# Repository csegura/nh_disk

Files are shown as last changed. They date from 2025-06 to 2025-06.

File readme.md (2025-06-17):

# NorthStar Advantage Hard Disk

This repository is made with the aim of completing a HardDisk Card for the NorthStar Advantage system. 

The idea is use a microcontroller (pi pico) to emulate a disk drive, allowing the NorthStar Advantage to read and write to a disk image stored on an SD card.

This is an ambitious project, as the NorthStar Advantage system is quite old and has a unique architecture, but it is a fun challenge. I am an enthusiast of retro computing and I want to see if I can make this work. So any help will be welcome.

Outside sure there a lot of other enthusiasts that would like to see this project completed, so welcome to the project!

## Current status

- The project is in the early stages of development.

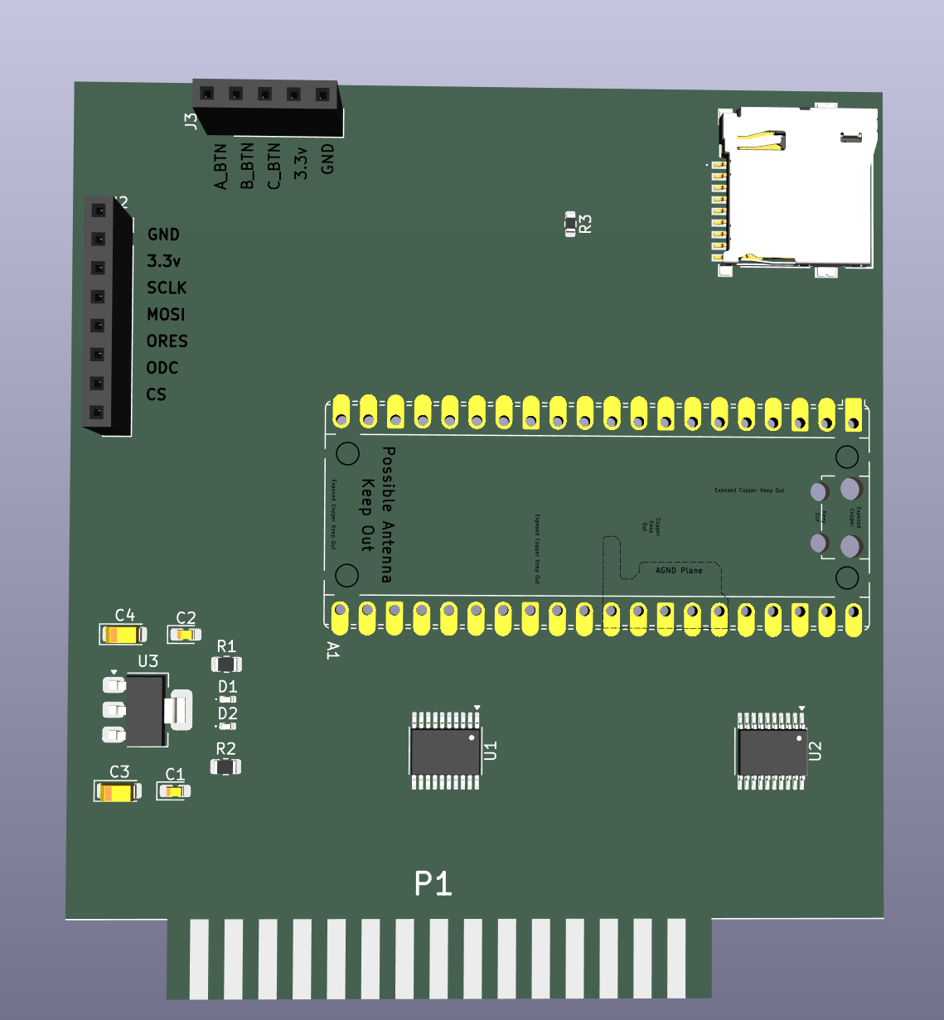
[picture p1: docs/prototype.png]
prototype


## Pi pico plan (code)

Continuously monitor the /SELECT line (via PIO) when /SELECT is asserted (low); and monitor the primary I/O control: 
/BRD (I/O Read), /BWR (I/O Write), /IDREQ (Board ID Read).

### Address decoding 
Capture the lower I/O address bits (IOA0–IOA3) (IOA3 is not used in HD controller) from the bus when an active cycle is detected. Get the target register.

### I/O reads 
Upon detecting an I/O read cycle (/SELECT low and /BRD low): 
- Push the captured port address (IOA0–IOA3) to the PIO's RX FIFO to notify the CPU and push the captured port address to the CPU's RX FIFO.
- Change the direction of the IOD0–IOD7 data lines to output while waiting for the CPU to write the requested data byte into the PIO's TX FIFO.
- Once the TX FIFO contains data, unblock it and drive the byte onto the IOD0–IOD7 lines.
- After /BRD goes high, change the direction of IOD0–IOD7 back to input (tristate).

### I/O writes 
Upon detecting an I/O write cycle (/SELECT low and /BWR low):
- Ensure that the IOD0–IOD7 lines are configured as inputs.
- Capture the port address (IOA0–IOA3) and push it to the RX FIFO.
- Obtain the data byte present on the IOD0–IOD7 lines.
- Push the data byte to the RX FIFO and notify the CPU.
- Wait for the /BWR signal to be deasserted (go high).

### Board ID 
Upon detecting an ID Read cycle (/SELECT low AND /IDREQ low)
- Push the relevant port address.

Once the CPU is informed take the actions read registers, read/write to sdcard.

## References

- [NorthStar Advantage ROMs dissasembly](https://github.com/dualityk/advantageroms)
- [Evan Allen's NorthStar Advantage Cards](https://github.com/abzman/Northstar-Advantage-Cards)

## Special thanks

- [Evan Allen](https://github.com/abzman) for the inspiration and initial work on the NorthStar Advantage cards and help me with the project.

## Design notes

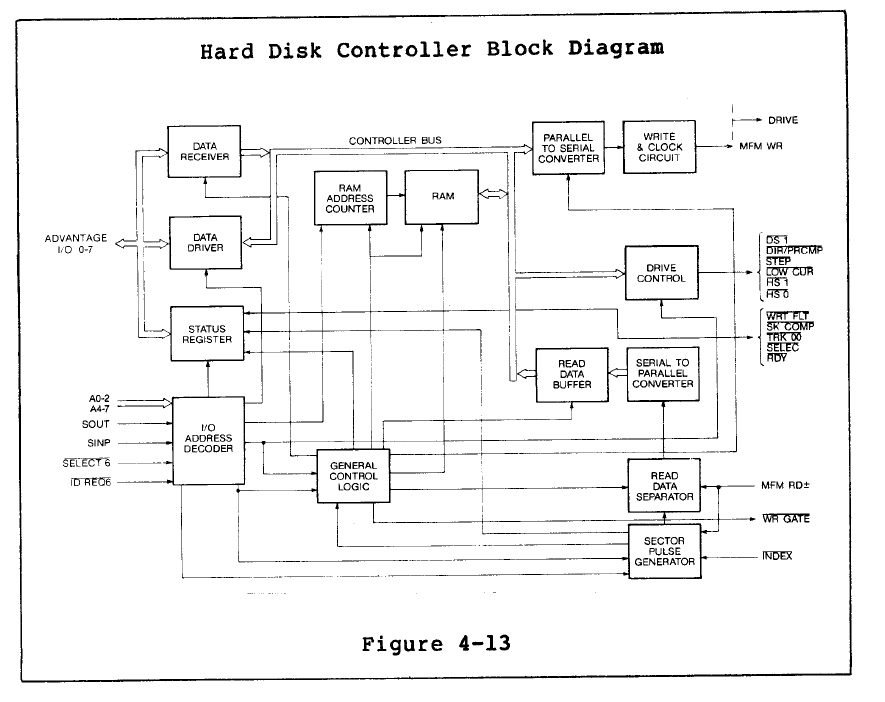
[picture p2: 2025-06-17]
docs/block_schema.png

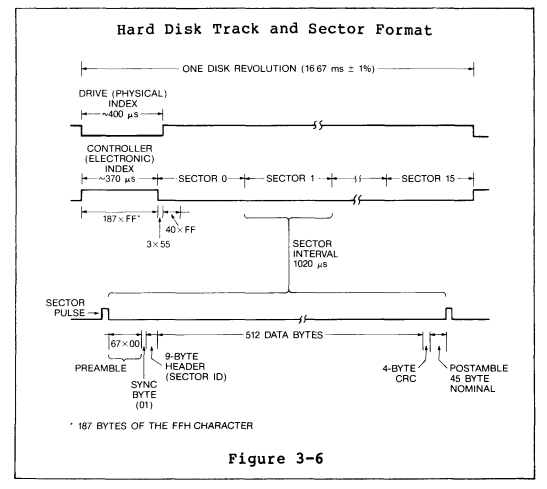
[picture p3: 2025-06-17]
docs/hd_track_sector.png

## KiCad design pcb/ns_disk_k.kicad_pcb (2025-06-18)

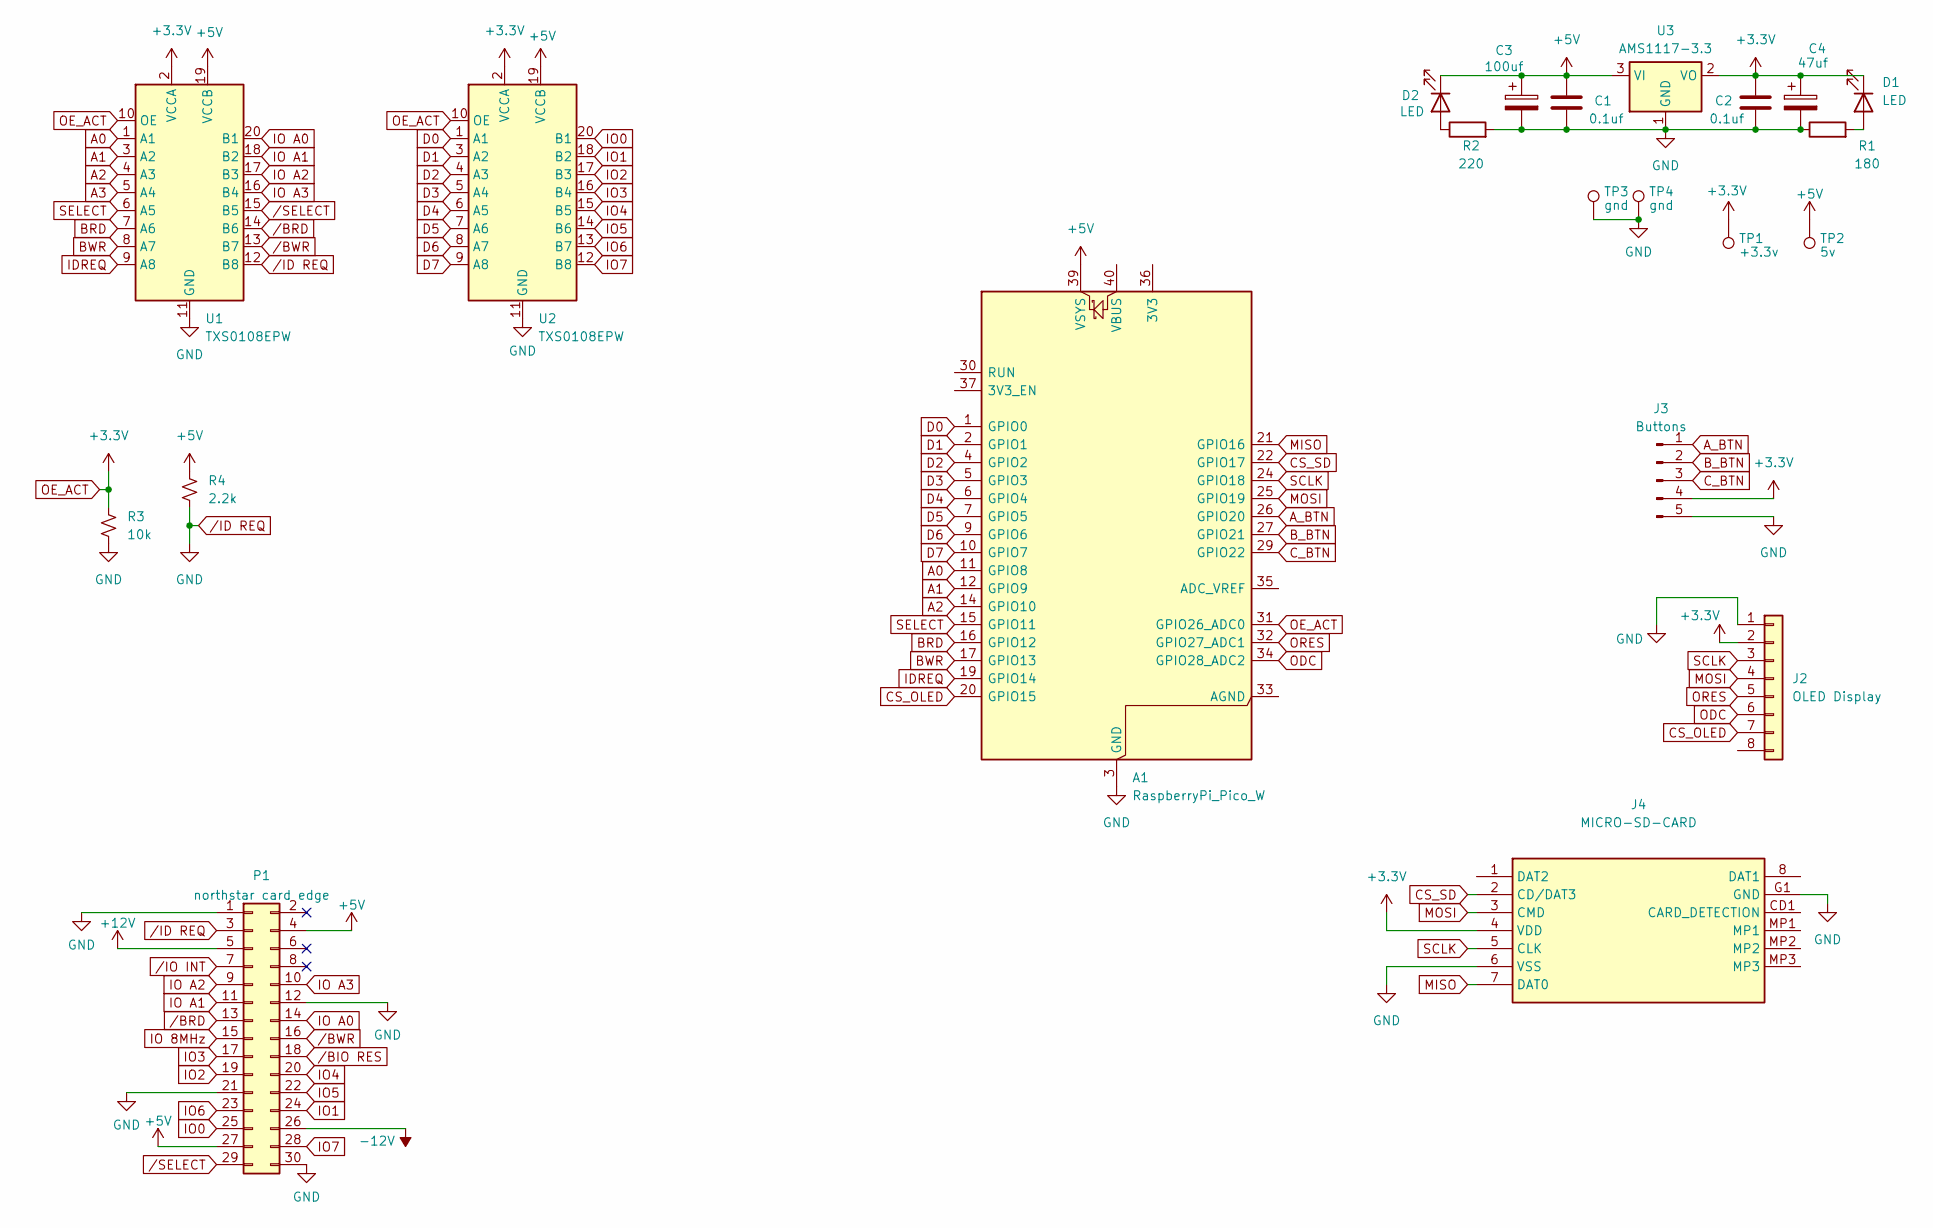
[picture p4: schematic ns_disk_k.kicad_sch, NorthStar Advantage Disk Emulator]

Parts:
A1: RaspberryPi_Pico_W; RaspberryPi_Pico_Common_Unspecified
C1, C2: 0.1uf; CP_EIA-1608-08_AVX-J_HandSolder
C3: 100uf; CP_EIA-3216-18_Kemet-A
C4: 47uf; CP_EIA-3216-18_Kemet-A
D1, D2: LED; LED_0402_1005Metric
J2: OLED Display; PinSocket_1x08_P2.54mm_Vertical
J3: Buttons; PinSocket_1x05_P2.54mm_Vertical
J4: MICRO-SD-CARD; MICROSDCARD; Manufacturer_Part_Number MICRO-SD-CARD; Mouser Part Number N/A
P1: northstar card edge; northstar edge connector
R1: 180; R_0805_2012Metric
R2: 220; R_0805_2012Metric
R3: 10k; R_0603_1608Metric
R4: 2.2k; R_0603_1608Metric
TP1: +3.3v; PinHeader_1x01_P2.54mm_Vertical
TP2: 5v; PinHeader_1x01_P2.54mm_Vertical
TP3, TP4: gnd; PinHeader_1x01_P2.54mm_Vertical
U1, U2: TXS0108EPW; TSSOP-20_4.4x6.5mm_P0.65mm
U3: AMS1117-3.3; SOT-223-3_TabPin2

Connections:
+5V: A1.39 (VSYS), C1.1, C3.1, D2.1 (K), P1.4, P1.27, R4.1, TP2.1, U1.19 (VCCB), U2.19 (VCCB), U3.3 (VI)
+12V: P1.5
-12V: P1.26
A0: A1.11 (GPIO8), U1.1 (A1)
A1: A1.12 (GPIO9), U1.3 (A2)
A2: A1.14 (GPIO10), U1.4 (A3)
A3: U1.5 (A4)
A_BTN: A1.26 (GPIO20), J3.1
BRD: A1.16 (GPIO12), U1.7 (A6)
BWR: A1.17 (GPIO13), U1.8 (A7)
B_BTN: A1.27 (GPIO21), J3.2
CS_OLED: A1.20 (GPIO15), J2.7
CS_SD: A1.22 (GPIO17), J4.2 (CD/DAT3)
C_BTN: A1.29 (GPIO22), J3.3
D0: A1.1 (GPIO0), U2.1 (A1)
D1: A1.2 (GPIO1), U2.3 (A2)
D2: A1.4 (GPIO2), U2.4 (A3)
D3: A1.5 (GPIO3), U2.5 (A4)
D4: A1.6 (GPIO4), U2.6 (A5)
D5: A1.7 (GPIO5), U2.7 (A6)
D6: A1.9 (GPIO6), U2.8 (A7)
D7: A1.10 (GPIO7), U2.9 (A8)
IDREQ: A1.19 (GPIO14), U1.9 (A8)
IO0: P1.25, U2.20 (B1)
IO1: P1.24, U2.18 (B2)
IO2: P1.19, U2.17 (B3)
IO3: P1.17, U2.16 (B4)
IO4: P1.20, U2.15 (B5)
IO5: P1.22, U2.14 (B6)
IO6: P1.23, U2.13 (B7)
IO7: P1.28, U2.12 (B8)
IO 8MHz: P1.15
IO A0: P1.14, U1.20 (B1)
IO A1: P1.11, U1.18 (B2)
IO A2: P1.9, U1.17 (B3)
IO A3: P1.10, U1.16 (B4)
MISO: A1.21 (GPIO16), J4.7 (DAT0)
MOSI: A1.25 (GPIO19), J2.4, J4.3 (CMD)
unnamed: D1.2 (A), R1.2
unnamed: D2.2 (A), R2.1
ODC: A1.34 (GPIO28_ADC2), J2.6
OE_ACT: A1.31 (GPIO26_ADC0), C2.1, C4.1, D1.1 (K), J2.2, J3.4, J4.4 (VDD), R3.1, TP1.1, U1.2 (VCCA), U1.10 (OE), U2.2 (VCCA), U2.10 (OE), U3.2 (VO)
ORES: A1.32 (GPIO27_ADC1), J2.5
SCLK: A1.24 (GPIO18), J2.3, J4.5 (CLK)
SELECT: A1.15 (GPIO11), U1.6 (A5)
/BIO RES: P1.18
/BRD: P1.13, U1.14 (B6)
/BWR: P1.16, U1.13 (B7)
/IO INT: P1.7
/SELECT: P1.29, U1.15 (B5)

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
Board: 2 copper layers, 22 parts (0 on the bottom side), 45 nets, no tracks yet.
